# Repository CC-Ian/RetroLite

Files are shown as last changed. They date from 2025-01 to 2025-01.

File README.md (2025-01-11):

# Retrolite
A retro themed segmented display with a built in driver.
<p align="center">
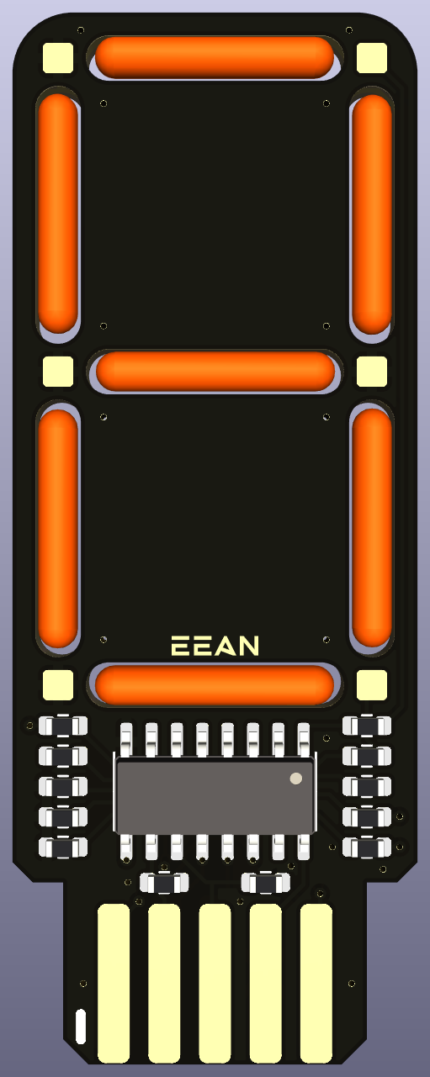
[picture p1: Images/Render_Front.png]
  
</p>

## Design Goals
- Chainable
- Easy to use
- Sleek
- Flicker free*
    - Depends on the state and frequency of the brightness control pin.

RetroLite stands as a continuation of my original 2.5 digit display, [InfiDig](https://github.com/CC-Ian/InfiDig-hardware). InfiDig was built around these very same LED Filaments, but required more resources to effectively manage. This is because InfiDig was charlieplexed using the host microcontroller. This caused flickering when chained in lengths of three or more, as seen on my [weather display](https://youtu.be/jOu5g1SzCnQ). 

RetroLite fixes the flicker issue by moving from a charlieplexed design to a direct-drive design. This makes these devices "Set and forget" as opposed to a device which requires a new framebuffer precisely every millisecond. In addition, this makes the display of arbitrary shapes or letters significantly easier to implement. Instead of breaking each shape down into three separate frames, you simply shift in an appropriate 8 bit pattern.

## Connections
It is recommended to connect RetroLite to a free SPI bus, however that is not exclusively necessary. Using your SPI bus will likely provide the highest rate of data throughput (up to a maximum of 100MHz depending on configuration. See [here](https://assets.nexperia.com/documents/data-sheet/74HC_HCT595.pdf)), but it is not strictly necessary, as the driver is a simple 8 bit serial to parallel shift register. It may provide an interesting effect to shift more slowly, fading the display into the next string you wish to display.

### Pinout
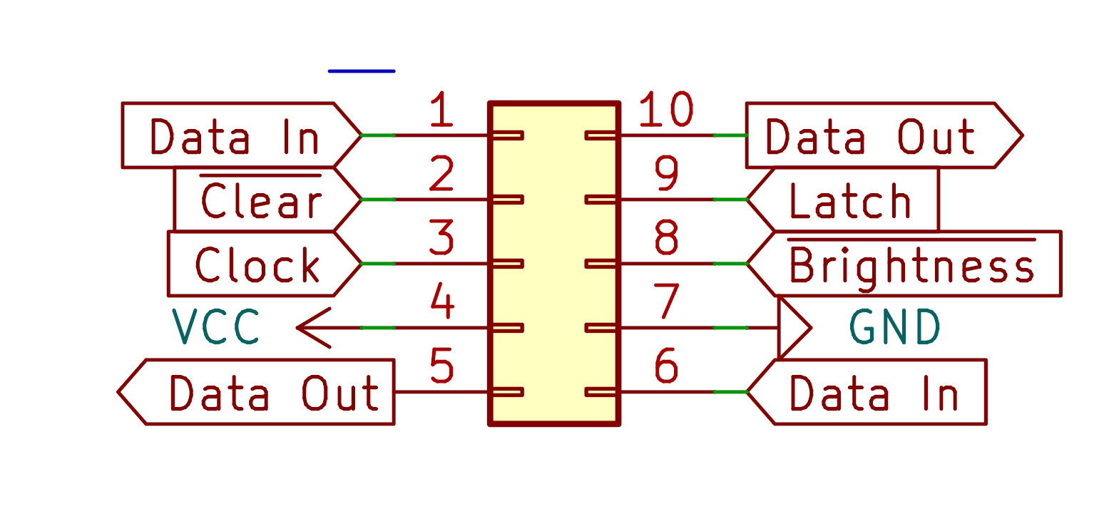
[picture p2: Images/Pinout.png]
Pinout


### Pin Numbering
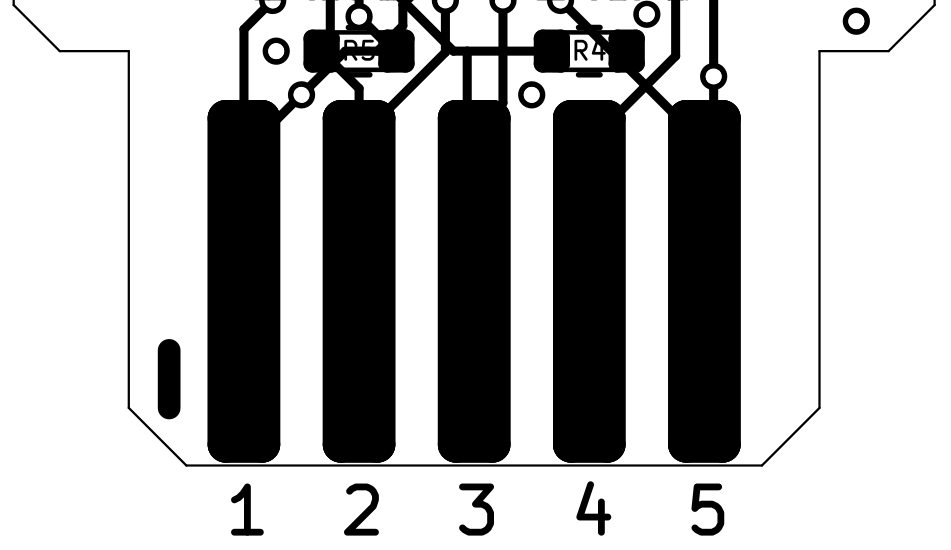
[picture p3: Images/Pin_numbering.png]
Pin Numbering


## Limitations
RetroLite maintains the same limitations as general seven segment displays, being unable to unambiguously display certain letters due to their shapes. See this [article](https://en.wikipedia.org/wiki/Seven-segment_display_character_representations) covering characters and their seven segment display representations.

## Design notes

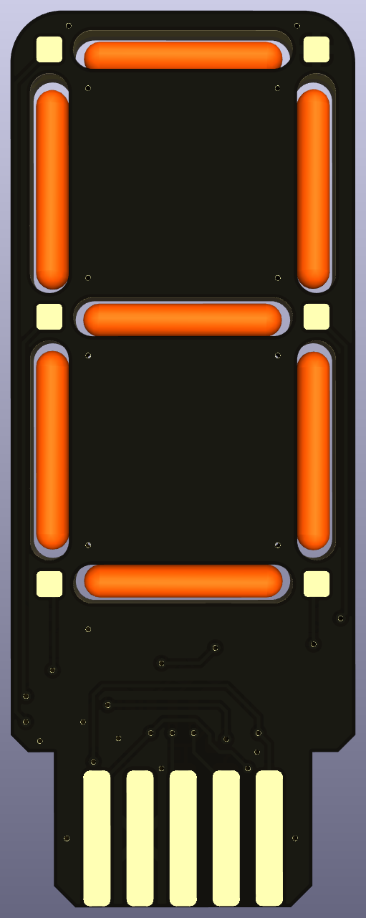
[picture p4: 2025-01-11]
Images/Render_Rear.png

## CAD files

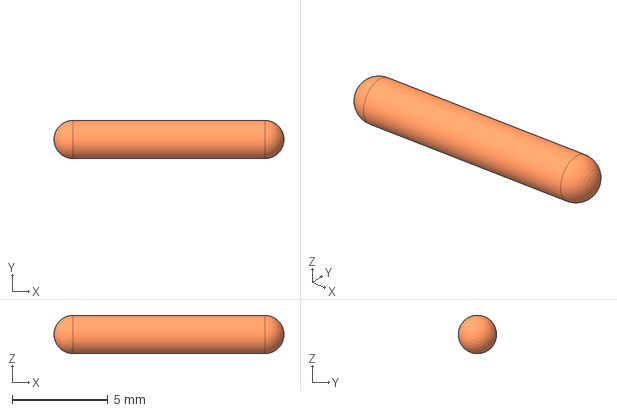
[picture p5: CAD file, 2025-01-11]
3D Models/LED Filament.step
12.0 x 2.00 x 2.00 mm

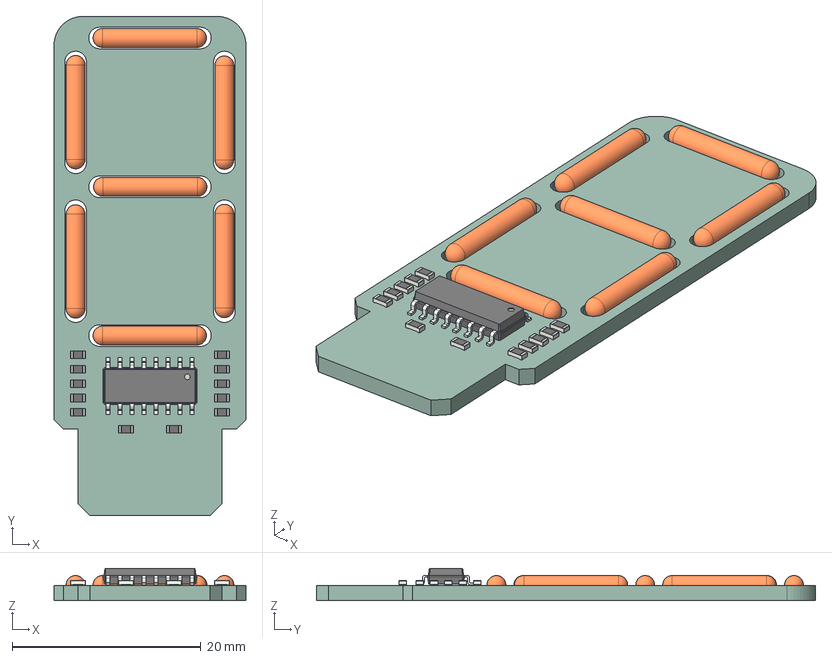
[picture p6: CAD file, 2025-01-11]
RetroLite.step
20.3 x 52.8 x 3.40 mm
R_0603_1608Metric x 12
SOIC_16_39x99mm_P127mm
RetroLite_PCB

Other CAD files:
3D Models/LED Filament.FCStd

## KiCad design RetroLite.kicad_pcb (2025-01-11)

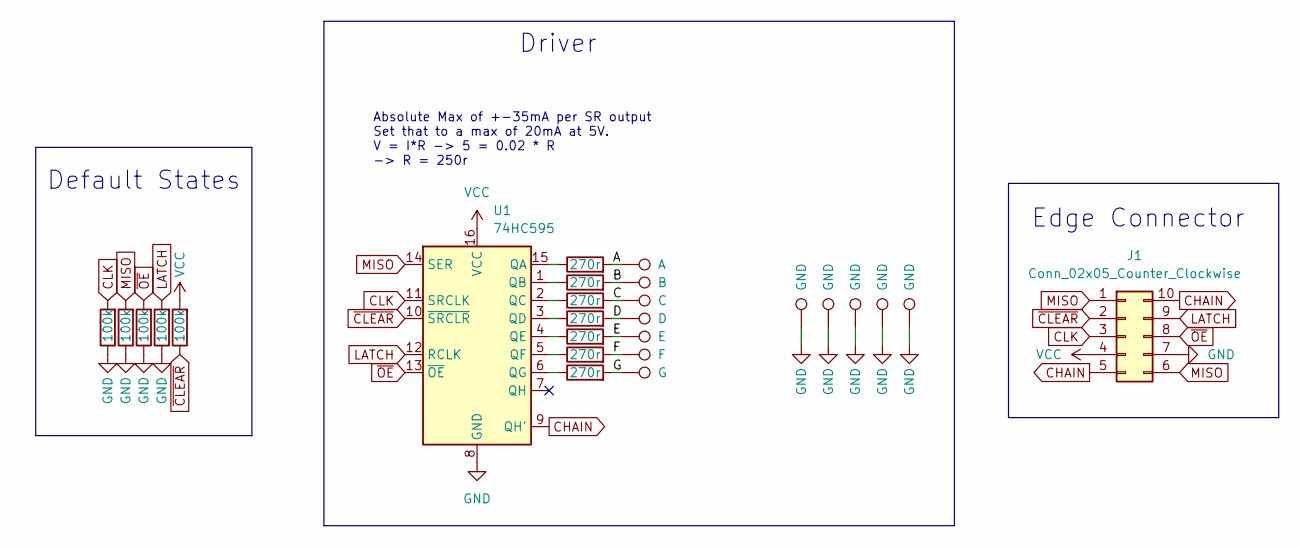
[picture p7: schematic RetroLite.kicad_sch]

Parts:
J1: Conn_02x05_Counter_Clockwise; edge-2.54-10p
R1, R2, R3, R4, R5: 100k; R_0603_1608Metric
R6, R7, R8, R9, R10, R11, R12: 270r; R_0603_1608Metric
TP2: A; led_landing_pad
TP3: B; led_landing_pad
TP4: C; led_landing_pad
TP5: D; led_landing_pad
TP6: E; led_landing_pad
TP7: F; led_landing_pad
TP8: G; led_landing_pad
TP9, TP10, TP11, TP12, TP13: GND; led_landing_pad
U1: 74HC595; SOIC-16_3.9x9.9mm_P1.27mm

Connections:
/A: R6.2, TP2.1
/B: R7.2, TP3.1
/C: R8.2, TP4.1
/D: R9.2, TP5.1
/E: R10.2, TP6.1
/F: R11.2, TP7.1
/G: R12.2, TP8.1
CHAIN: J1.5, J1.10, U1.9 (QH')
CLK: J1.3, R4.2, U1.11 (SRCLK)
GND: J1.7, R1.1, R2.1, R3.1, R4.1, TP9.1, TP10.1, TP11.1, TP12.1, TP13.1, U1.8 (GND)
LATCH: J1.9, R1.2, U1.12 (RCLK)
MISO: J1.1, J1.6, R3.2, U1.14 (SER)
unnamed: R6.1, U1.15 (QA)
unnamed: R7.1, U1.1 (QB)
unnamed: R8.1, U1.2 (QC)
unnamed: R9.1, U1.3 (QD)
unnamed: R10.1, U1.4 (QE)
unnamed: R11.1, U1.5 (QF)
unnamed: R12.1, U1.6 (QG)
VCC: J1.4, R5.2, U1.16 (VCC)
~CLEAR: J1.2, R5.1, U1.10 (~SRCLR)
~OE: J1.8, R2.2, U1.13 (~OE)

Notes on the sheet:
Default States
Absolute Max of +-35mA per SR output Set that to a max of 20mA at 5V. V = I*R -> 5 = 0.02 * R -> R = 250r
Driver
Edge Connector

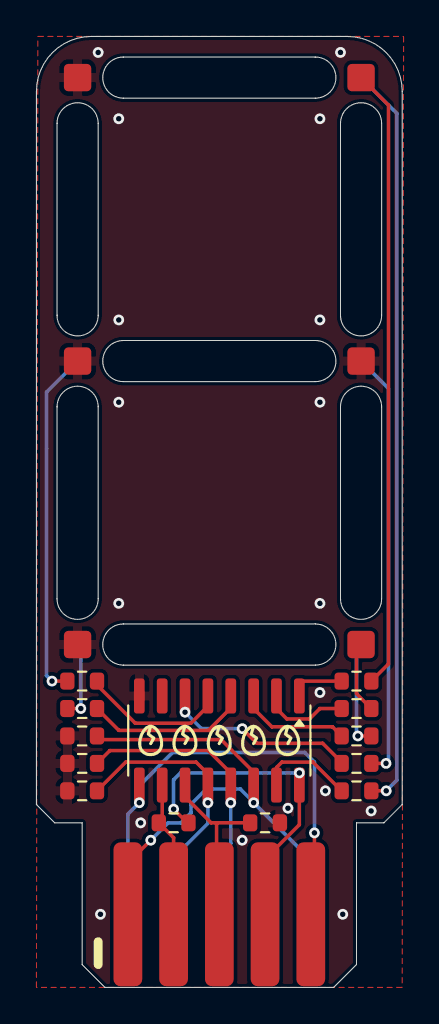
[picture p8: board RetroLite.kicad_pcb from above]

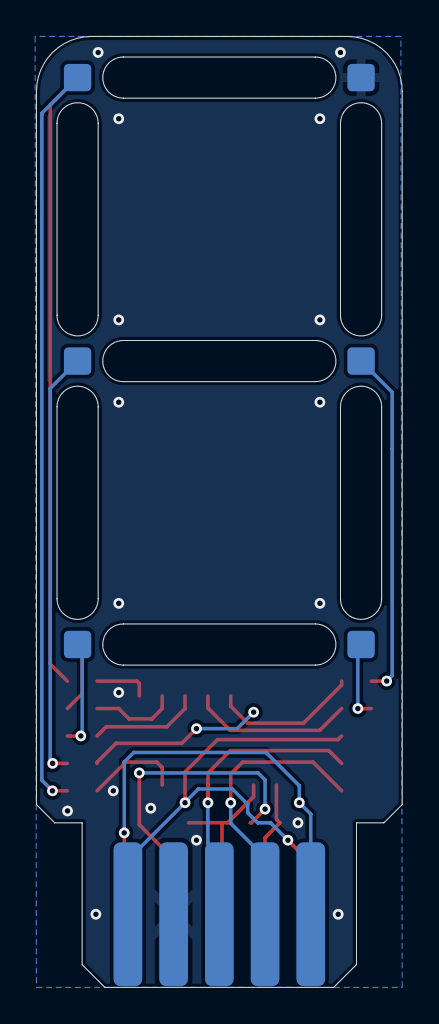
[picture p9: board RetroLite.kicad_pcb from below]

Board: 2 copper layers, 20.3 x 52.8 mm, 26 parts (6 on the bottom side), 22 nets.

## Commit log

2025-01-11 add kicad gitignore
2025-01-11 Add final board design
    [RetroLite.kicad_pcb, RetroLite.kicad_sch]
2025-01-11 Generate and add gerbers
    [RetroLite-B_Cu.gbr, RetroLite-B_Mask.gbr, RetroLite-B_Paste.gbr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]
2025-01-11 Add filament models; Ignore freecad backups
    [RetroLite.kicad_pcb]
2025-01-11 Add filament models; Add renders
    [LED Filament.FCStd, LED Filament.step]
2025-01-11 Update filaments to 'through hole'
    [RetroLite.kicad_pcb]
2025-01-11 Add step file for assembled RetroLite
    [RetroLite.step]
2025-01-11 Add Pin Numbering
